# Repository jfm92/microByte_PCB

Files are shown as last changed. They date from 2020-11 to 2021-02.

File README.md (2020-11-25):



This repository contains the schematics and the PCB design of the microByte project with **KiCad 5.1.6.**

The 3D model of the components were obtained from [SnapEDA](https://www.snapeda.com/).

**If you want to know more about the microByte project go to the next link:**
[Github microByte](https://github.com/jfm92/microByte)

## 3D PCB Images

### PCB Front View
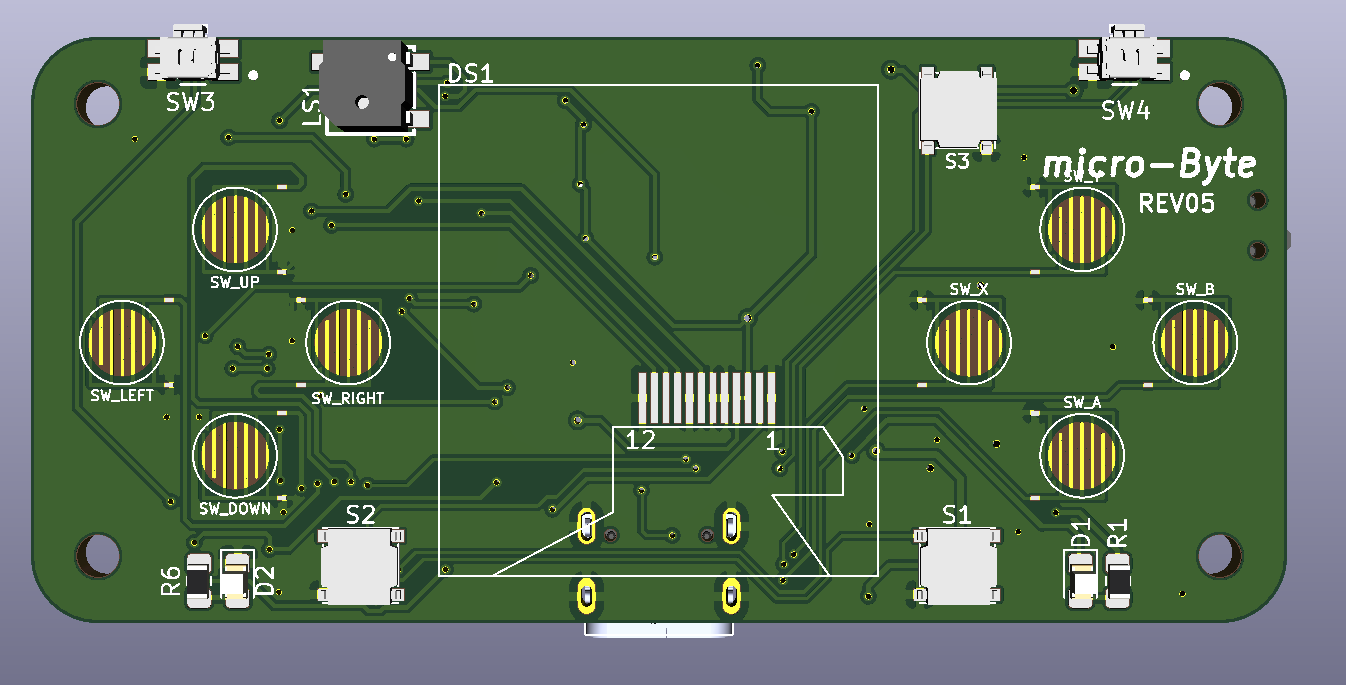
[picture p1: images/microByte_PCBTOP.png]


### PCB Bottom View
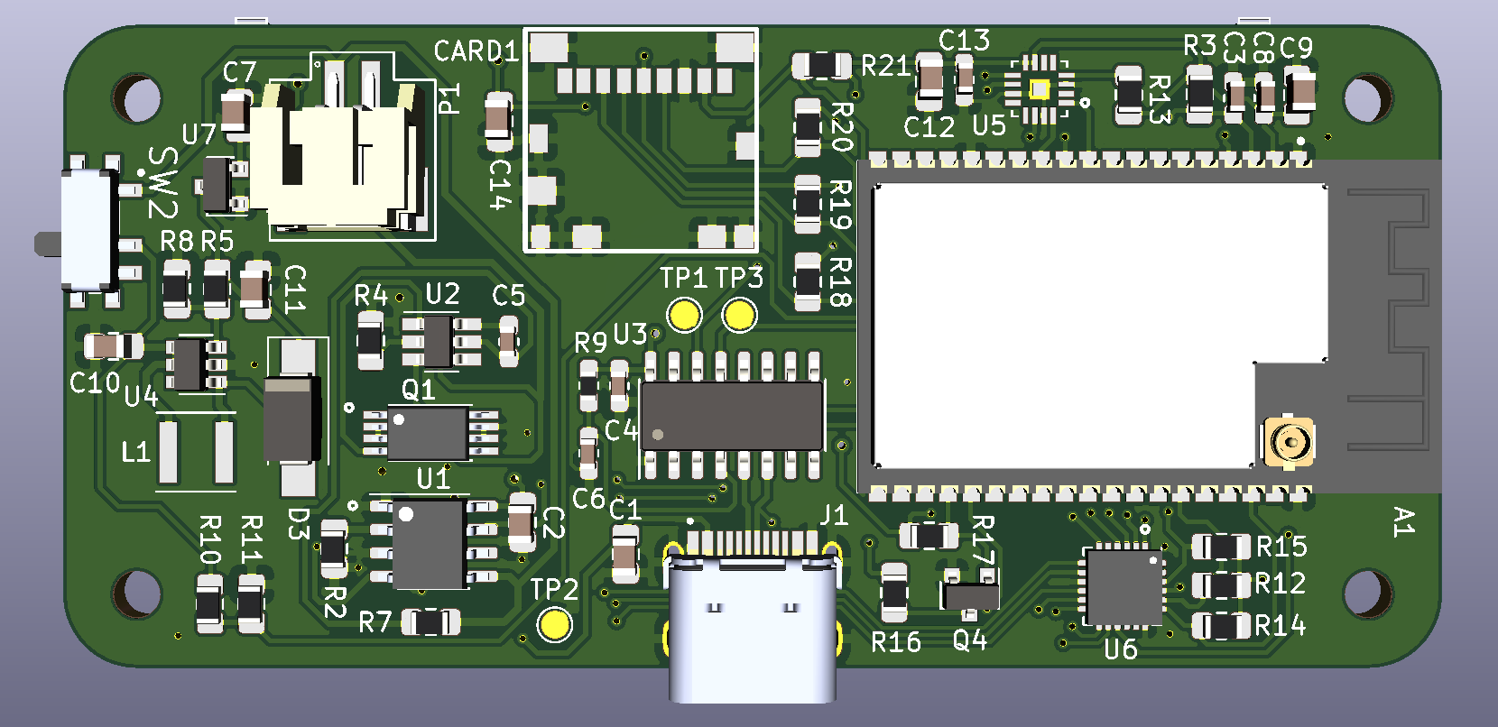
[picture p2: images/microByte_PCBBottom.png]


Note: Some of the compenent 3D models weren't available, thats the reason why they don't appear on the PCB.

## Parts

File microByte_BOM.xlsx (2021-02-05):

Reference | Quantity | Designatation | Package | Link
A1 | 1 | ESP32-WROVER-E (16MB ) | - | Espressif Systems|Espressif Systems ESP32-WROVER-E(16MB)|WIFI Modules|LCSC (https://lcsc.com/product-detail/WIFI-Modules_Espressif-Systems-ESP32-WROVER-E-16MB_C529589.html)
C1 | 1 | 1uF | C_0805_2012Metric
C11 C10 | 2 | 22uF | C_0805_2012Metric
C12 C14 C9 C2 | 4 | 10uF | C_0805_2012Metric
C13 C8 C3 C5 C6 C4 | 6 | 0.1uF | C_0603_1608Metric
C7 | 1 | 10uF | C_0805_2012Metric
CARD1 | 1 | TF-110 | -
D1 D2 | 2 | LED | LED_0805_2012Metric
D3 | 1 | D_Schottky | D_SMA
DS1 | 1 | ST7789 1.3" | -
H1 H2 H3 H4 | 4 | MountingHole | -
J1 | 1 | TYPE-C-31-M-12 | -
L1 | 1 | 22uH | -
LS1 | 1 | Speaker | - | KELIKING|KELIKING KLJ-5030|Buzzers|LCSC (https://lcsc.com/product-detail/Buzzers_KELIKING-KLJ-5030_C201044.html)
P1 | 1 | S2B-PH-SM4-TB | - | Ckmtw(Shenzhen Cankemeng)|Ckmtw(Shenzhen Cankemeng) C132500|Wire To Board / Wire To Wire Connector|LCSC (https://lcsc.com/product-detail/Wire-To-Board-Wire-To-Wire-Connector_Ckmtw-Shenzhen-Cankemeng-C132500_C132500.html)
Q1 | 1 | FS8205A | SOP65P640X120-8N | Fortune Semicon|Fortune Semicon FS8205A|MOSFET|LCSC (https://lcsc.com/product-detail/MOSFET_Fortune-Semicon-FS8205A_C16052.html)
Q4 | 1 | BSS138 | SOT-23
R1 R6 R2 | 3 | 1K | R_0805_2012Metric
R10 | 1 | 12K | R_0805_2012Metric
R11 | 1 | 27K | R_0805_2012Metric
R13 | 1 | 1M | R_0805_2012Metric
R16 | 1 | 10R | R_0805_2012Metric
R17 | 1 | 3K | R_0805_2012Metric
R18 R19 R20 R21 R12 R14 R15 R3 R5 | 9 | 10K | R_0805_2012Metric
R4 | 1 | 1k | R_0805_2012Metric
R7 | 1 | 100R | R_0805_2012Metric
R8 | 1 | 2K | R_0805_2012Metric
R9 | 1 | 0R | R_0805_2012Metric
S1 | 1 | SW_START | -
S2 | 1 | SW_SELECT | -
S3 | 1 | SW_MENU | -
SW10 | 1 | SW_X | -
SW11 | 1 | SW_RIGHT | -
SW12 | 1 | SW_Y | -
SW2 | 1 | PCM12SMTR | - | Korean Hroparts Elec|Korean Hroparts Elec K3-1296S-E2|Toggle Switches|LCSC (https://lcsc.com/product-detail/Toggle-Switches_Korean-Hroparts-Elec-K3-1296S-E2_C136659.html)
SW3 | 1 | SW_L | - | ALPSALPINE|ALPSALPINE SKSCLCE010|Tactile Switches|LCSC (https://lcsc.com/product-detail/Tactile-Switches_ALPS-Electric-SKSCLCE010_C139799.html)
SW4 | 1 | SW_R | - | ALPSALPINE|ALPSALPINE SKSCLCE010|Tactile Switches|LCSC (https://lcsc.com/product-detail/Tactile-Switches_ALPS-Electric-SKSCLCE010_C139799.html)
SW5 | 1 | SW_UP | -
SW6 | 1 | SW_A | -
SW7 | 1 | SW_DOWN | -
SW8 | 1 | SW_B | -
SW9 | 1 | SW_LEFT | -
TP1 | 1 | TP_RST | -
TP2 | 1 | TP_GND | -
TP3 | 1 | TP_IO0 | -
U1 | 1 | TP4056 | ESOP8 | TOPPOWER(Nanjing Extension Microelectronics)|TOPPOWER(Nanjing Extension Microelectronics) TP4056-42-ESOP8|PMIC - Battery Management|LCSC (https://lcsc.com/product-detail/PMIC-Battery-Management_TOPPOWER-Nanjing-Extension-Microelectronics-TP4056-42-ESOP8_C16581.html)
U2 | 1 | FS312F-G | SOT-23-6 | Fortune Semicon|Fortune Semicon FS312F-G|Battery Protection ICs|LCSC (https://lcsc.com/product-detail/Battery-Protection-ICs_Fortune-Semicon-FS312F-G_C82736.html)
U3 | 1 | CH340C | SOIC-16 | WCH(Jiangsu Qin Heng)|WCH(Jiangsu Qin Heng) CH340C|USB ICs|LCSC (https://lcsc.com/product-detail/USB-ICs_WCH-Jiangsu-Qin-Heng-CH340C_C84681.html)
U4 | 1 | MT3608 | SOT-23-6 | XI'AN Aerosemi Tech|XI'AN Aerosemi Tech MT3608|DC-DC Converters|LCSC (https://lcsc.com/product-detail/DC-DC-Converters_XI-AN-Aerosemi-Tech-MT3608_C84817.html)
U5 | 1 | MAX98357AETE+T | TQFN
U6 | 1 | TCA9555RTWR | 24-Pin WQFN
U7 | 1 | MCP1700-3302E_SOT23 | SOT-23

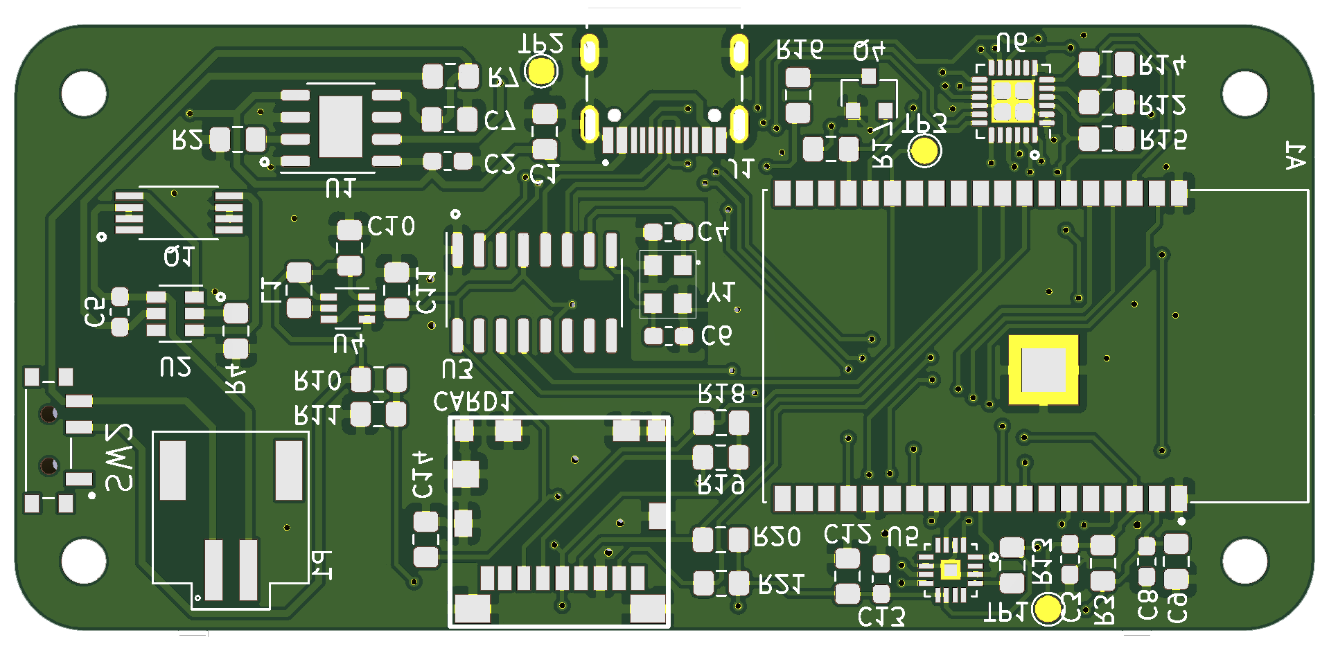
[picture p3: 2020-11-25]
components_3d/micro-Byte_bottom_flipped.png

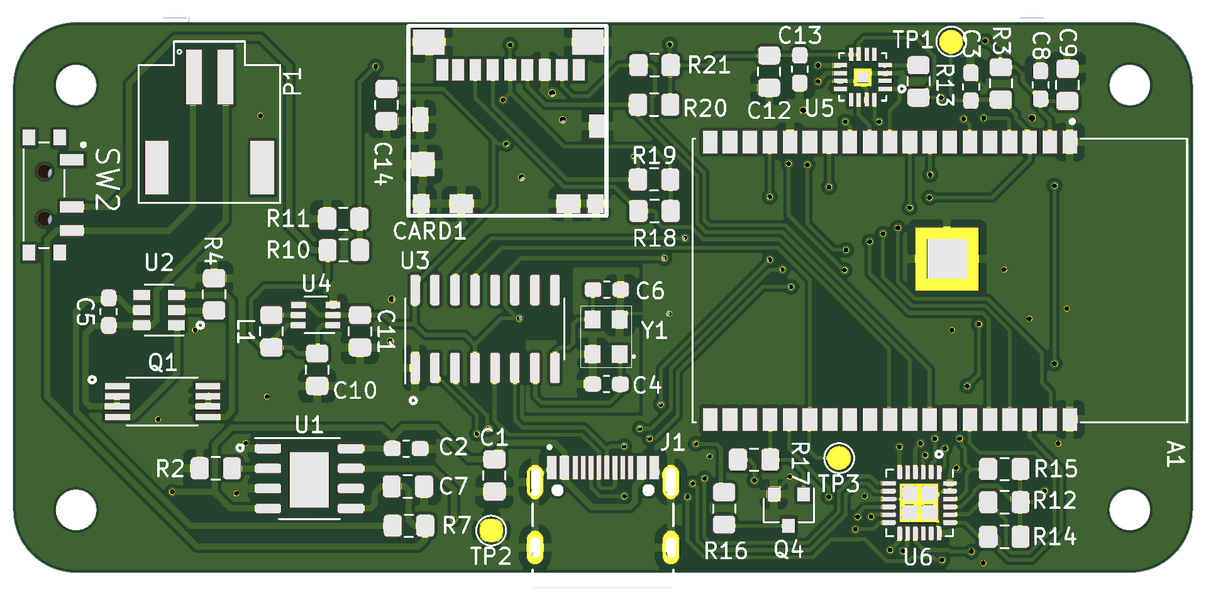
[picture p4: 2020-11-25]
components_3d/micro-Byte_bottom.png

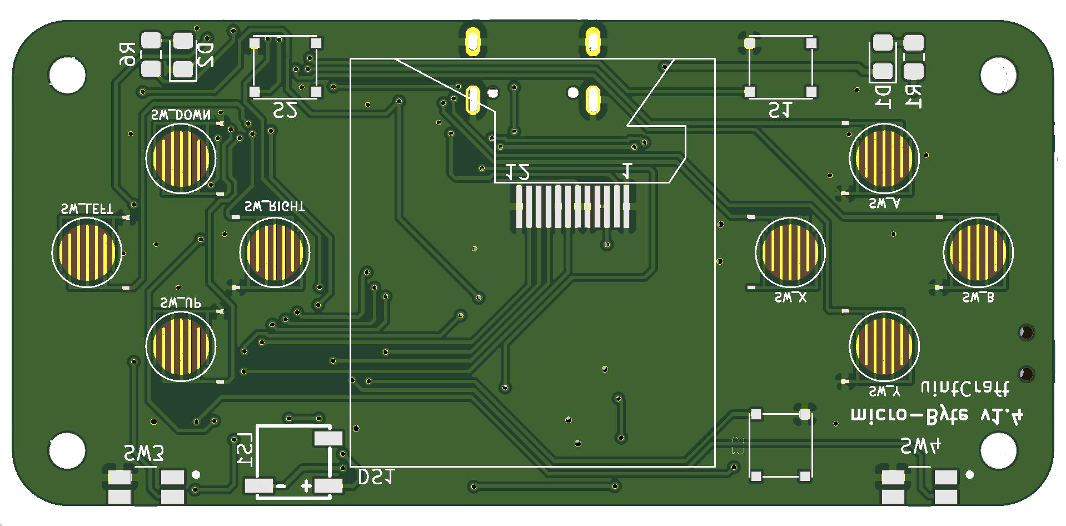
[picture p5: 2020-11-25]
components_3d/micro-Byte_front0_flipped.png

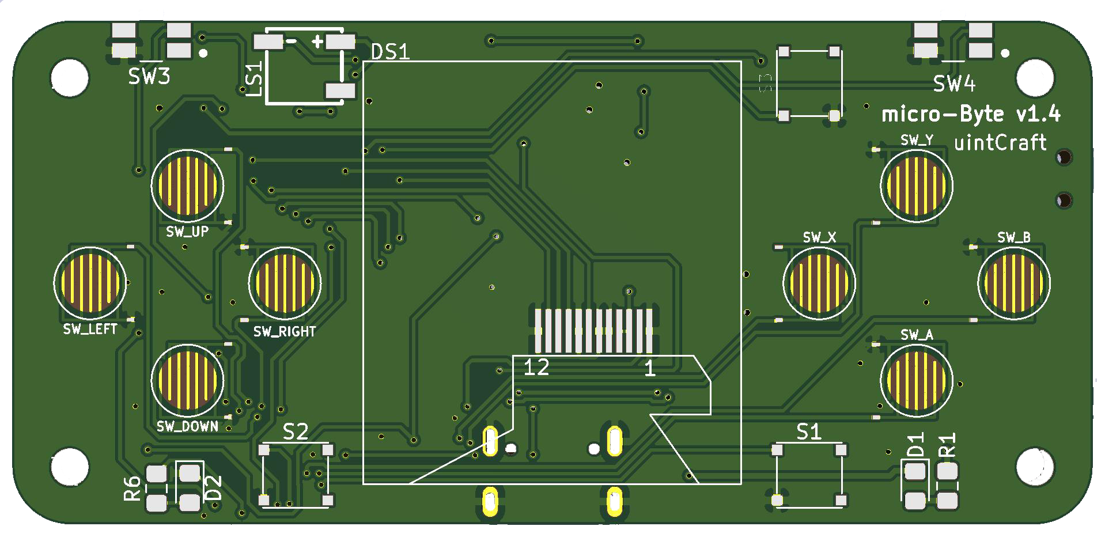
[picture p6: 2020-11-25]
components_3d/micro-Byte_front.png

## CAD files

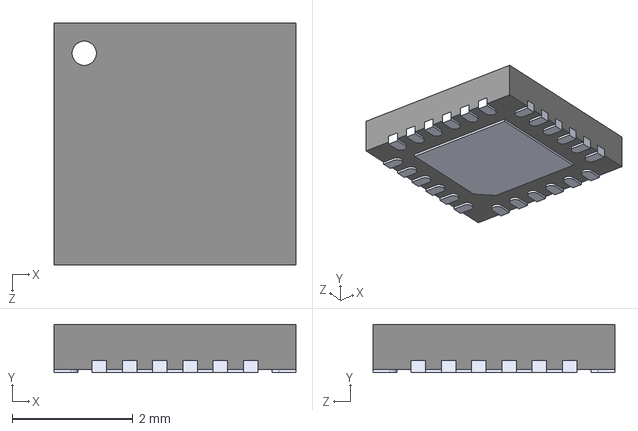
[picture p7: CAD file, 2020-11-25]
components_3d/TCA9555RTWR.STEP
4.00 x 0.8 x 4.00 mm

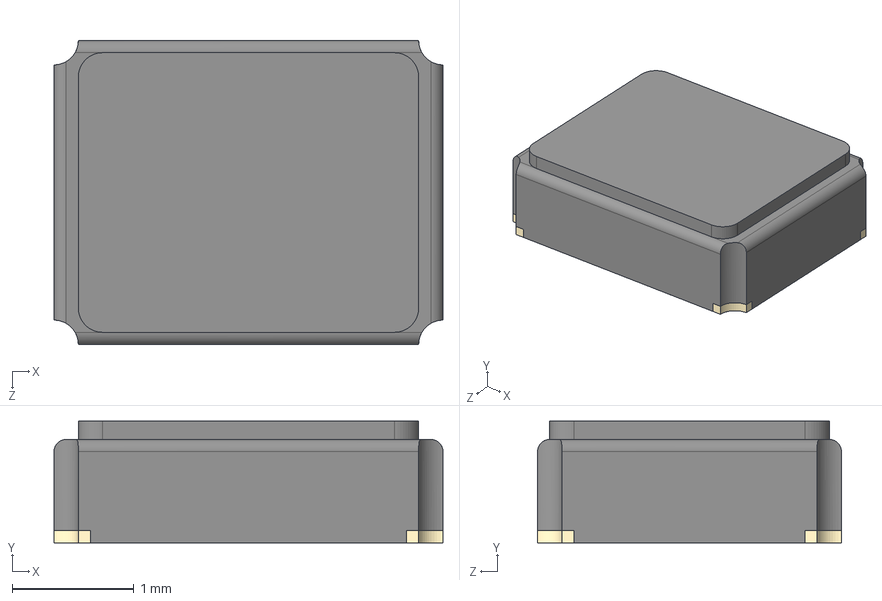
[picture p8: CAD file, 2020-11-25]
components_3d/ABM8-12.000MHZ-B2-T.STEP
3.20 x 1.00 x 2.50 mm

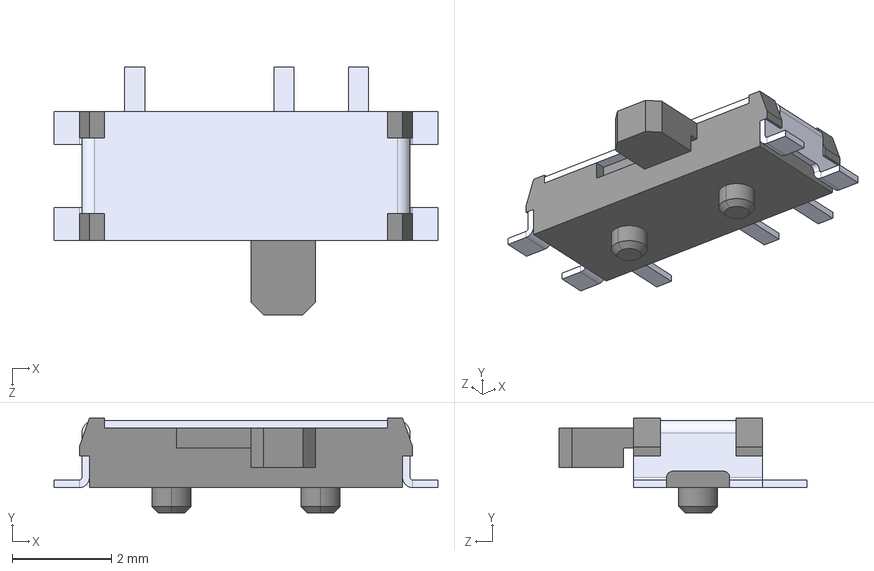
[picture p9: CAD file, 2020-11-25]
components_3d/PCM12SMTR.STEP
7.72 x 1.91 x 4.98 mm

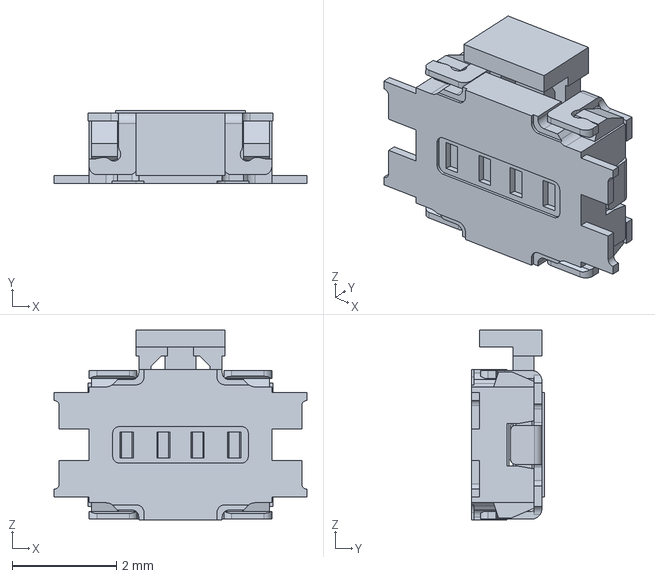
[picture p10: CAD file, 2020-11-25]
components_3d/PTS841GKSMTRLFS.stp
4.85 x 1.40 x 3.64 mm

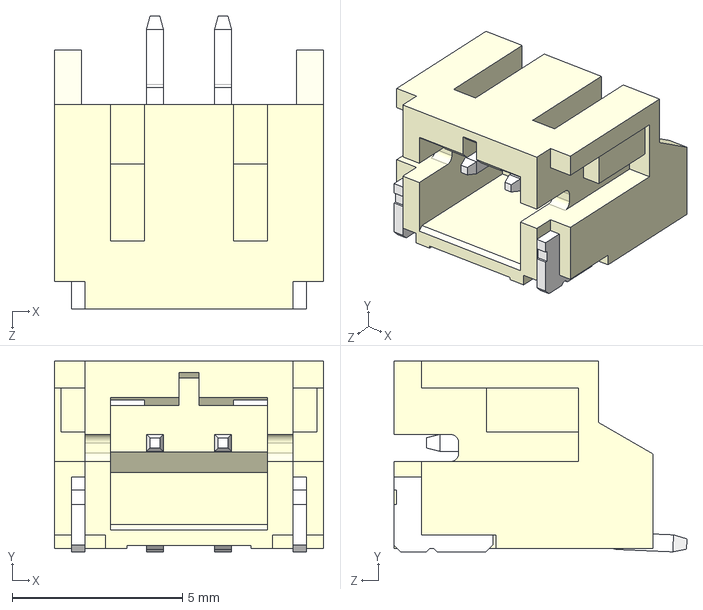
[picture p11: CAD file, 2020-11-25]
components_3d/S2B-PH-SM4-TB(LF)(SN).STEP
7.90 x 5.60 x 8.60 mm

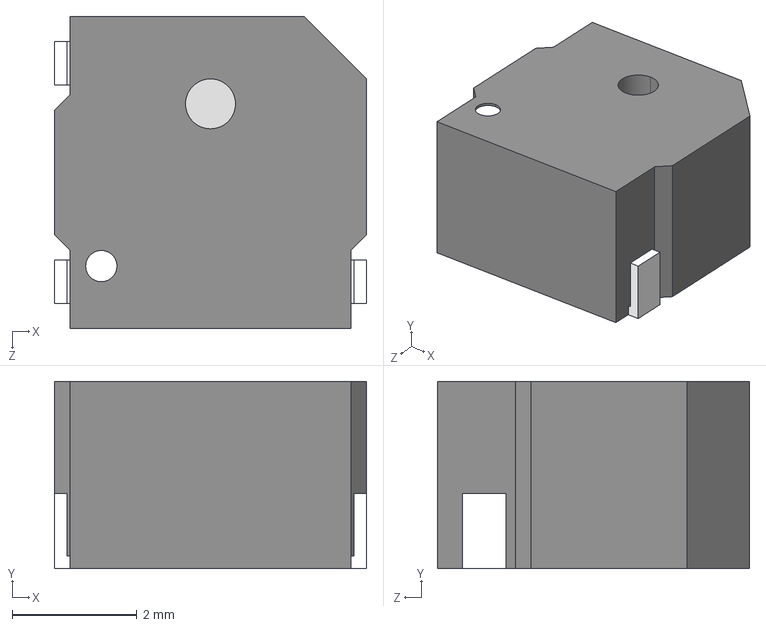
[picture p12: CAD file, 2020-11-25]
components_3d/CUI_DEVICES_CSS-0578-SMT-TR.step
5.00 x 3.00 x 5.00 mm

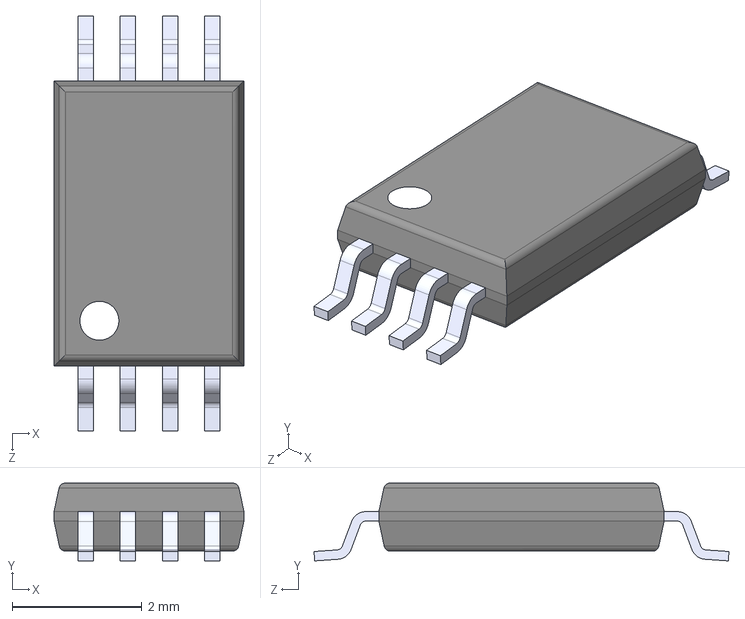
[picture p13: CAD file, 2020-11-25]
components_3d/FS8205A.STEP
2.93 x 1.20 x 6.40 mm

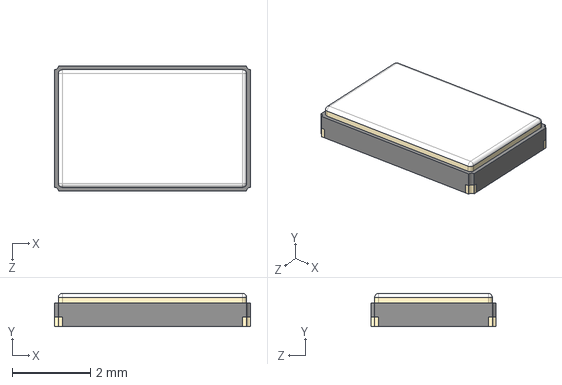
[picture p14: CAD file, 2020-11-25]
components_3d/ECS-120-20-30B-TR.STEP
5.00 x 0.85 x 3.20 mm

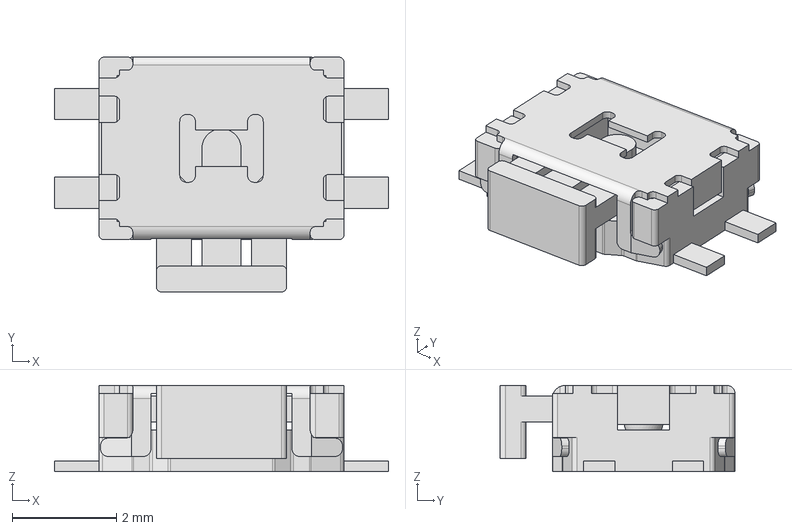
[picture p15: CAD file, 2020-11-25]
components_3d/TL1014AFxxxQG.stp
6.40 x 4.50 x 1.65 mm

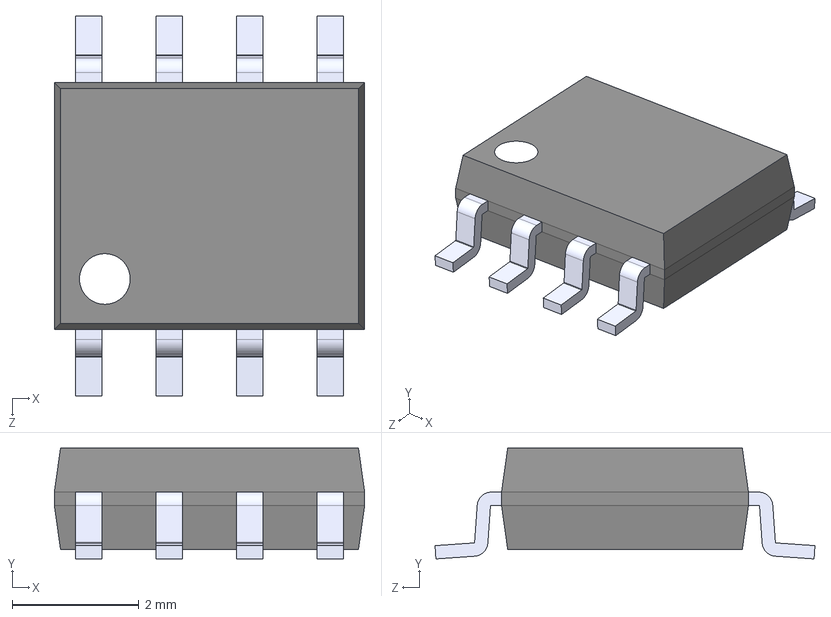
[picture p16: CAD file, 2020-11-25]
components_3d/TP4056.STEP
4.90 x 1.75 x 6.00 mm

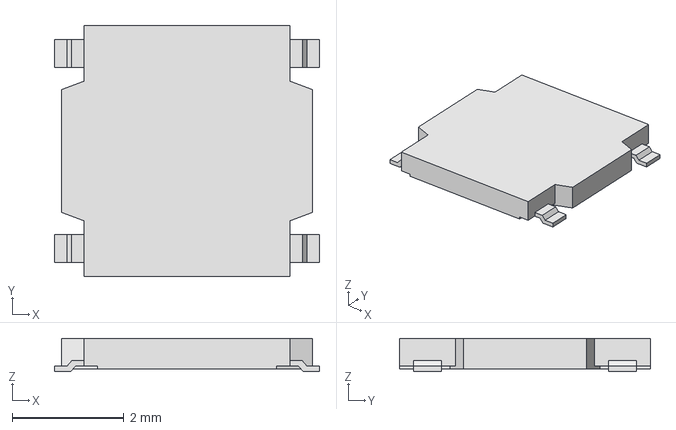
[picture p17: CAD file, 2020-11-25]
components_3d/TL3315NFxxxQ.stp
4.75 x 4.50 x 0.6 mm

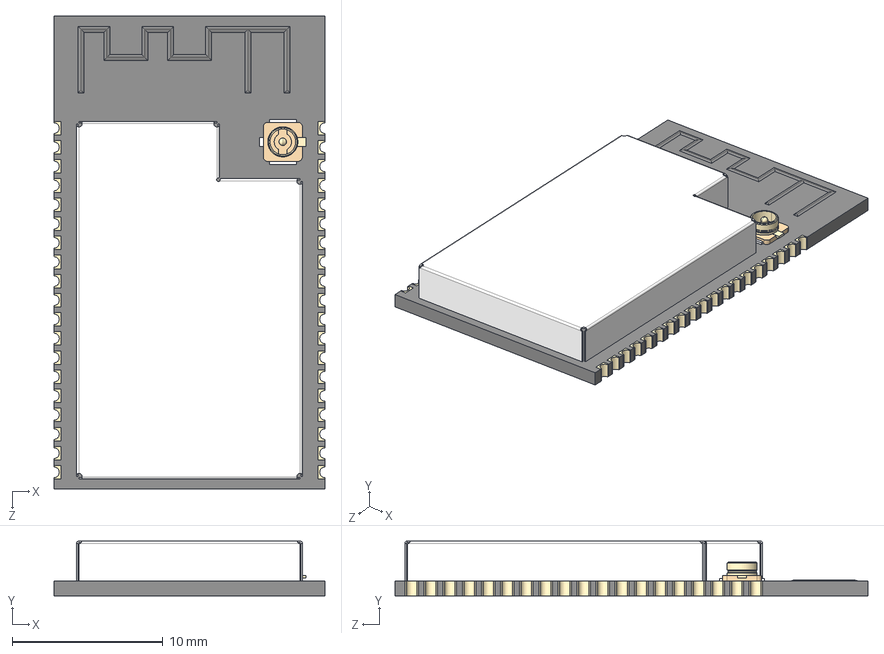
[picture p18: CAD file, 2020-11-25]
components_3d/ESP32-WROVER-I.STEP
18.0 x 3.65 x 31.4 mm

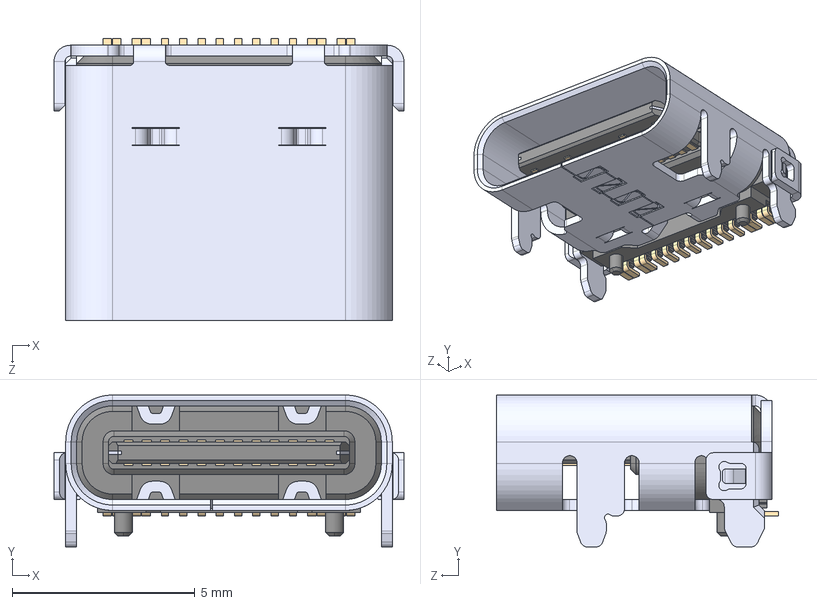
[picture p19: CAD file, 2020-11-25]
components_3d/USB4105-GF.STEP
9.58 x 4.16 x 7.71 mm

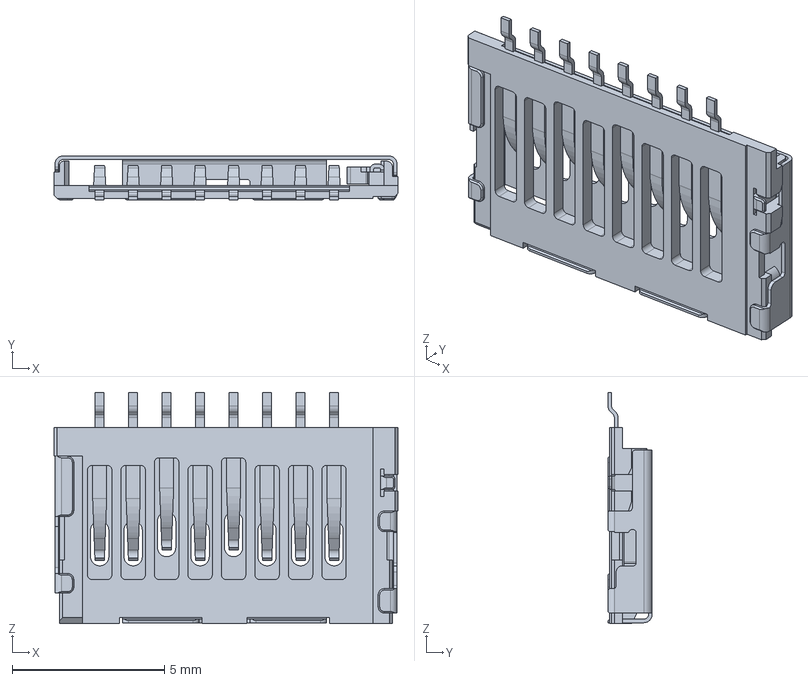
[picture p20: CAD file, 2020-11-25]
components_3d/1051620001.stp
11.3 x 1.45 x 7.60 mm

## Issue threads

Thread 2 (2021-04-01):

About the V3 pin of CH340C

Jiawens, 2021-04-01:
In the schematic, near the CH340C chip, there is a sentence like this:

> R9 brigde to connect to +3.3v.
Is not clear on datatsheet.

I went to search for the datasheet of CH340C, it says:

> 当使用 3.3V 工作电压时，CH340 芯片的 V3 引脚应该与 VCC 引脚相连接，同时输入外部的 3.3V 电源，并且与 CH340 芯片相连接的其它电路的工作电压不能超过 3.3V。

After translation:

> When using 3.3V working voltage, V3 pin of CH340 chip should be connected with VCC pin, and input external 3.3V power supply at the same time, and the working voltage of other circuits connected with CH340 chip should not exceed 3.3V.

It didn't said that R9 should bridge to connect to +3.3V, so I am a little bit doubtful. Will it work when V3 pin is connected to +3.3v directly?

(Sorry for my poor English and bad grammer)

jfm92, 2021-04-08:
Hi Jiawens,
Sorry for the delayed answer, I'm a little busy nowadays.

> It didn't said that R9 should bridge to connect to +3.3V, so I am a little bit doubtful. Will it work when V3 pin is connected to +3.3v directly?

On previous versions of the board, V3 and Vcc were connected, and it worked. But the reason to add a bridge was that the chip was producing an "Electrical noise" and I was suspecting that the datasheet was badly translated, and the information was wrong. (This is the datasheet [Sparkfun translation](https://cdn.sparkfun.com/datasheets/Dev/Arduino/Other/CH340DS1.PDF) )

At this moment I don't connect V3 and VCC, and it works fine. No audible electrical noise, and no issue with RTC and CTS signals.

Maybe this answer can help you too much, but I just can say that it works fine.

redfox67, 2021-04-08:
If i were to add a headphone jack, would I add it before or after the amp to the speaker? does the speaker have an amp or is it in the audio chip?

Jiawens, 2021-04-17:
I see. I will use the same design as yours to avoid electrical noise.
Thank you for your comment. :)

Closed 2021-04-17.

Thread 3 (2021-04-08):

Add headphone jack

redfox67, 2021-04-08:
If I were to add a headphone jack were would I solder it to? I am thinking about using [this one](https://www.amazon.com/Adafruit-Vertical-Breadboard-Friendly-Headphone/dp/B07M7PGL99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).

jfm92, 2021-04-12:
Hi!
Well, I'm not sure if the jack that you're thinking to use fits inside the enclosure, but if you think that it's possible or you can find something a little bit smaller, you need to do the next:

- Solder directly to the driver it's very difficult due to the pads are very small, so I suggest to first unsolder the speaker.
- Once you have unsoldered the speaker, these are the sound output pads:
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

I think that the easiest way, is to add a pair of wires and place the jack on the bottom part of the enclosure because the front has very little space available and might be a real challenge to fit a jack there. Also, I think that can help you a little see the 3D model of the enclosure to visualize the internal space.
https://github.com/jfm92/microByte_case/tree/2df587d479643be42f094e5c9a5782840cb68b26/Enclosure

I hope this message can help you and I'm anxious to see your experiment!

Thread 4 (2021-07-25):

Easily Broken switch

kicker22004, 2021-07-25:
My unit arrived yesterday and was damaged from heat exposure, I've left you a comment on crowdsource with this information, upon reprinting the cases and getting the unit back together the Right toggle feel off the switch taking the inner plunger with it so that switch is going to need to be replaced now, I'm going to redesign the button so that it fits inside the case with two lips instead of one so that the button doesn't need glued to the switch head. I'm hoping that my other one doesn't fail also. And on further inspection my power switch is bent down I'm not sure if it's from heat or the pressure from the case but i'll be replacing it and making changes to the case if needed.

redfox67, 2021-07-25:
I had a similar issue, the right switch was not working on arrival. Overconfident in my making skills I tried to fix it and broke the switch. That is a great idea to do a redesigned button, if you do get that done could I use that file? Also do you know the switches name/number?

kicker22004, 2021-07-25:
> I had a similar issue, the right switch was not working on arrival. Overconfident in my making skills I tried to fix it and broke the switch. That is a great idea to do a redesigned button, if you do get that done could I use that file? Also do you know the switches name/number?

https://lcsc.com/mobile/product-detail/Tactile-Switches_ALPS-Electric-SKSCLCE010_C139799.html
That is the link to the switch, also it seems there was already a button redesign 3 months ago. I printed the new design yesterday but can't test until my switches get here. I know the other switch is going to break trying to remove the printed button so I ordered 5 switches just in case.

redfox67, 2021-07-26:
Thank you, how hard do you think it would be to desolder the switch as opposed to cutting it off?

kicker22004, 2021-07-26:
For me it is very simple but I have a bit of experience working with SMD.

redfox67, 2021-07-26:
Yeah, I ended up crushing the switch then removed it, however when I tried soldering a replacement button I had on hand the continuity check showed that there was a bridge between the control wire and ground. After desoldering and trying to fix it , it still is linked to ground. either I tell the firmware that one of the menu buttons is the right switch or I route a different pin on the u6 to the button which is an even more difficult soldering job. What would you recommend I do?

kicker22004, 2021-07-26:
I would remove your switch and then test the pads, those shouldn't be touching, after that test the switch off the board as well.

redfox67, 2021-07-26:
I tried testing the pads, what I believe to be the problem is that the pad that is connected to the u6 is soldered to the sheet of copper in the pcb that is grounded.

kicker22004, 2021-07-26:
Oh that's unfortunate, I'd reach out to the creator but if you damaged it then it's on you.

jfm92, 2021-07-26:
Hi!

Sorry for taking so long to follow up on this issue.
The U6 is solder the cooper plain to dissipate heat, to unsolder it I recommend using a heat gun instead of an iron solder, it can be very challenging :)
Anyways, I don't fully understand the relation with switch issue and the U6? Are you trying to use the PCB buttons to switch the power?
If it so, I don't recommend you to do so, because the switch just connect the battery circuit with the rest of the rest of PCB so it's just like join to wires.
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

redfox67, 2021-07-26:
Thank you for responding, the issue is the right bumper/trigger thing, What happened is in the schematic the switch is between ground and pin 6 of U6, or the controls IC and if I run a continuity check of those two solder pads they are connected without there even being a switch, which means that in any game that uses that button it will be permanently triggered.

redfox67, 2021-07-26:
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

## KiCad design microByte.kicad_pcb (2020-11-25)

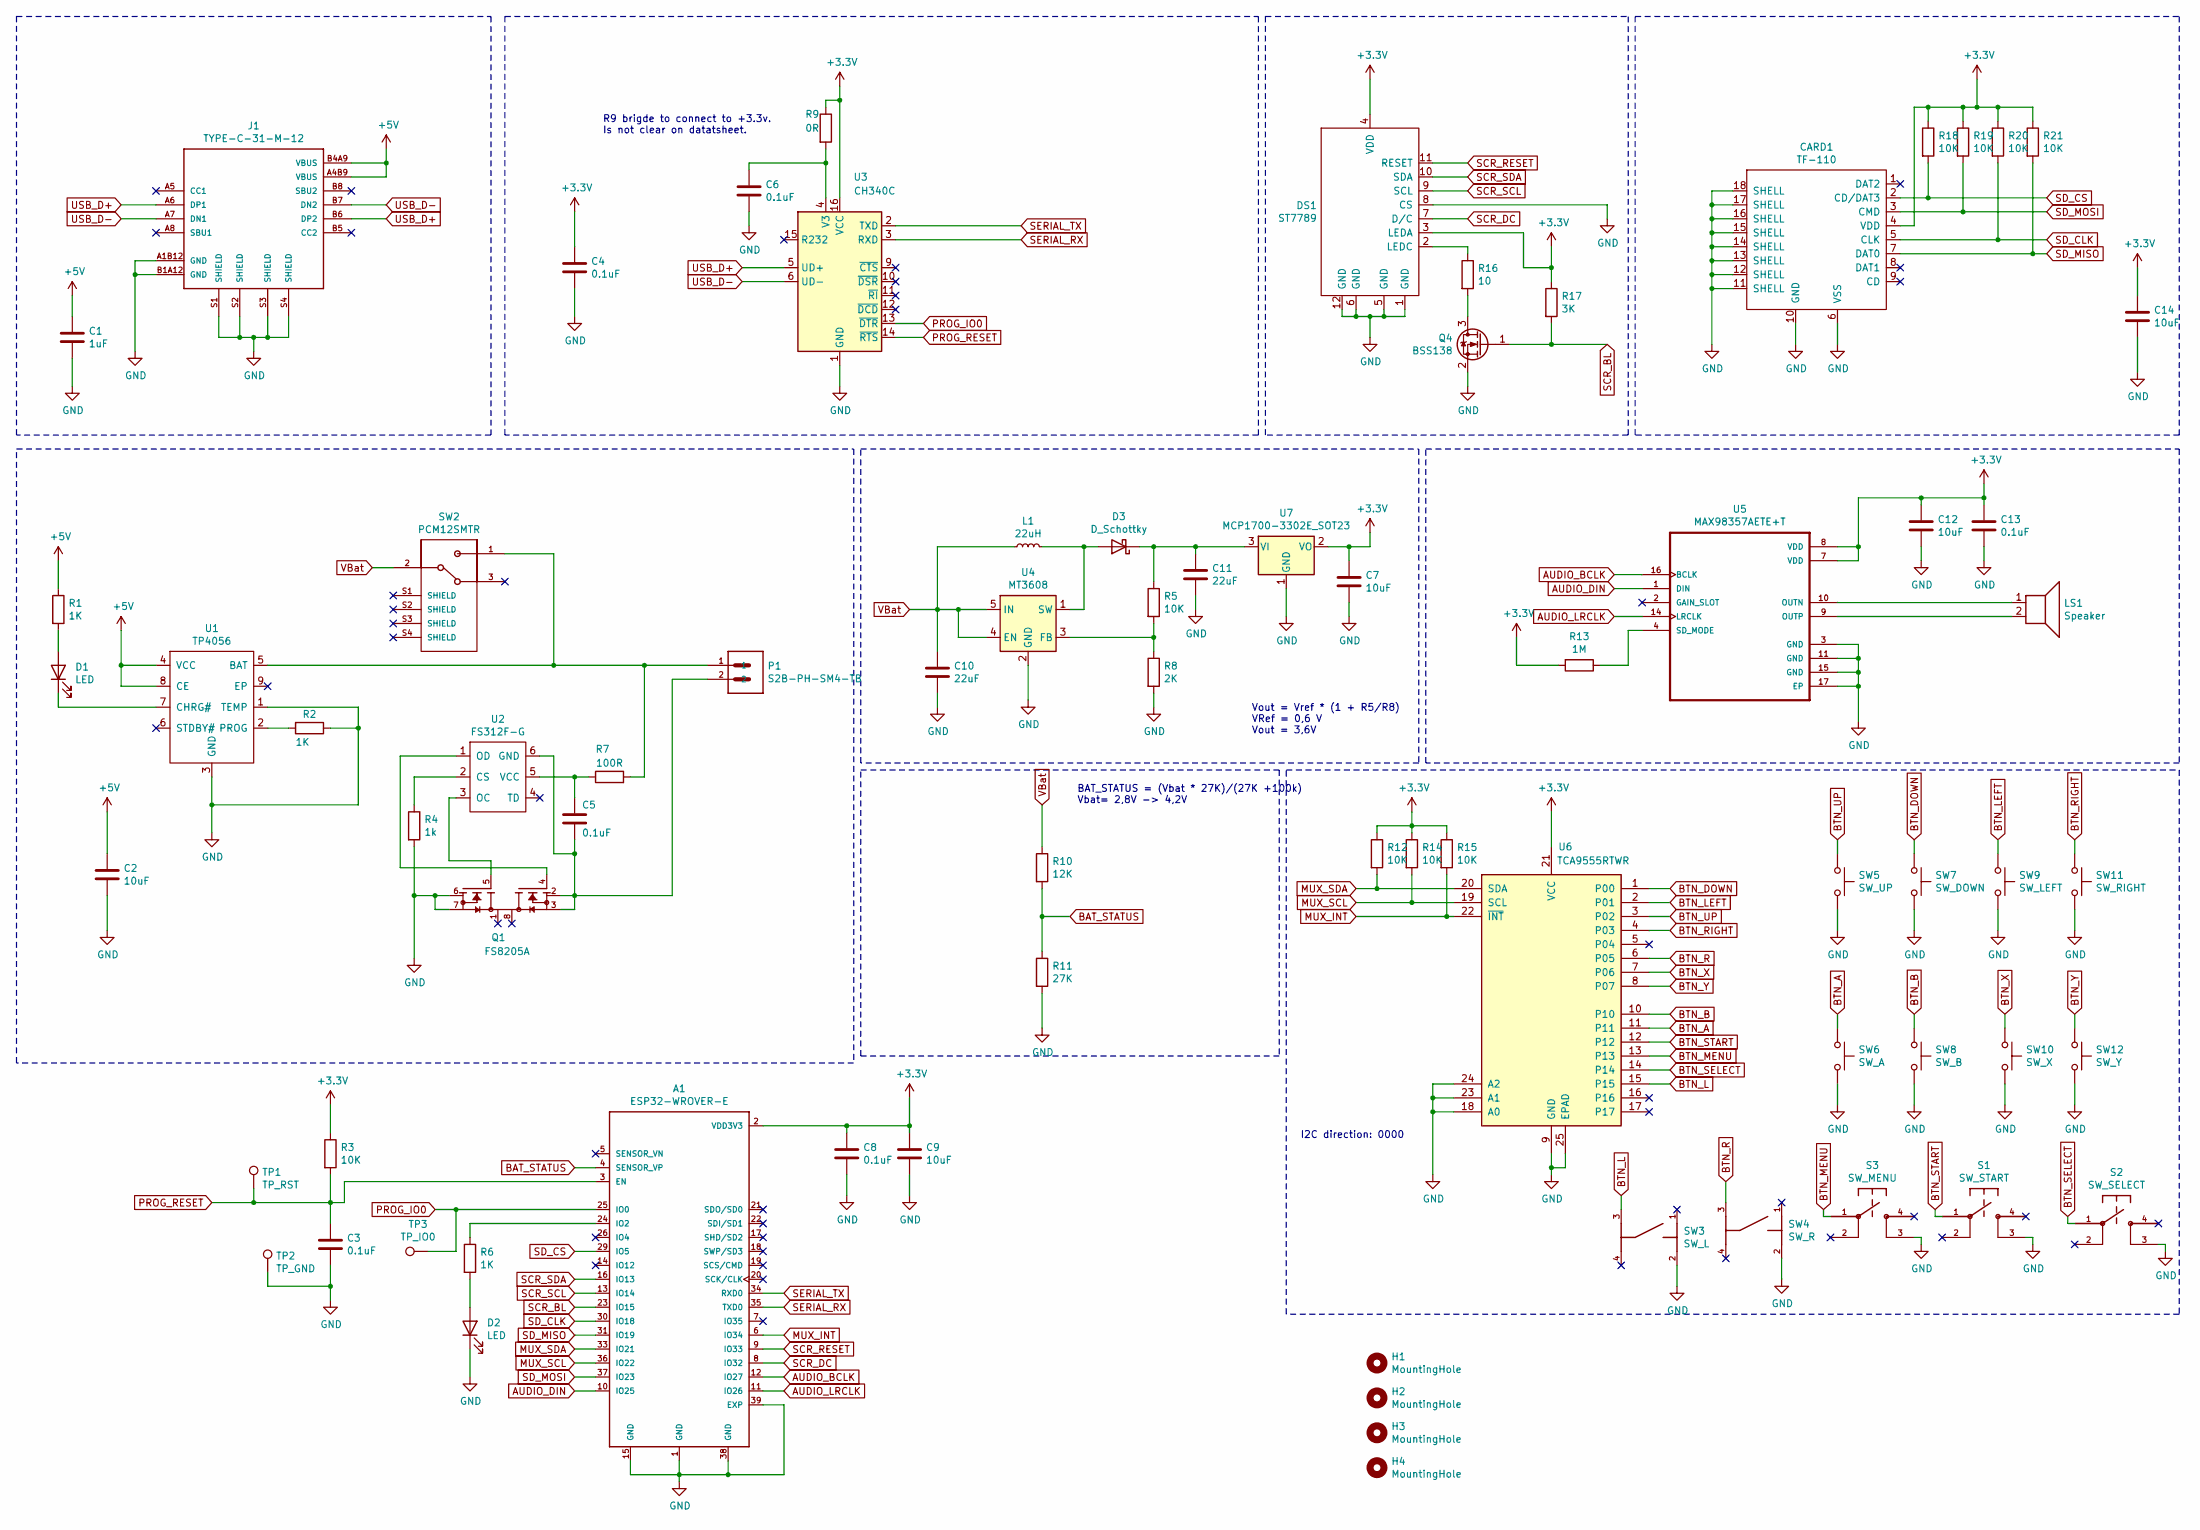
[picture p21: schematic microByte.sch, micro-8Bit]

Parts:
A1: ESP32-WROVER-E; XCVR_ESP32-WROVER-I
C1: 1uF; C_0805_2012Metric_Pad1.15x1.40mm_HandSolder
C2, C9, C12, C14: 10uF; C_0805_2012Metric_Pad1.15x1.40mm_HandSolder
C3, C4, C5, C6, C8, C13: 0.1uF; C_0603_1608Metric_Pad1.05x0.95mm_HandSolder
C7: 10uF; C_0805_2012Metric
C10, C11: 22uF; C_0805_2012Metric_Pad1.15x1.40mm_HandSolder
CARD1: TF-110
D1, D2: LED; LED_0805_2012Metric_Pad1.15x1.40mm_HandSolder
D3: D_Schottky; D_SMA_Handsoldering
DS1: ST7789
H1, H2, H3, H4: MountingHole; MountingHole_2.5mm
J1: TYPE-C-31-M-12; HRO_TYPE-C-31-M-12
L1: 22uH; Sunlord_SPH4012H220MT
LS1: Speaker; KLJ-5030
P1: S2B-PH-SM4-TB; JST_S2B-PH-SM4-TB
Q1: FS8205A; SOP65P640X120-8N
Q4: BSS138; SOT-23
R1, R2, R6: 1K; R_0805_2012Metric_Pad1.15x1.40mm_HandSolder
R3, R5, R12, R14, R15, R18, R19, R20, R21: 10K; R_0805_2012Metric_Pad1.15x1.40mm_HandSolder
R4: 1k; R_0805_2012Metric_Pad1.15x1.40mm_HandSolder
R7: 100R; R_0805_2012Metric_Pad1.15x1.40mm_HandSolder
R8: 2K; R_0805_2012Metric_Pad1.15x1.40mm_HandSolder
R9: 0R; R_0603_1608Metric_Pad1.05x0.95mm_HandSolder
R10: 12K; R_0805_2012Metric_Pad1.15x1.40mm_HandSolder
R11: 27K; R_0805_2012Metric_Pad1.15x1.40mm_HandSolder
R13: 1M; R_0805_2012Metric_Pad1.15x1.40mm_HandSolder
R16: 10; R_0805_2012Metric_Pad1.15x1.40mm_HandSolder
R17: 3K; R_0805_2012Metric_Pad1.15x1.40mm_HandSolder
S1: SW_START; TL3315NF100Q
S2: SW_SELECT; TL3315NF100Q
S3: SW_MENU; TL3315NF100Q
SW2: PCM12SMTR; SW_PCM12SMTR
SW3: SW_L; SW_434331013822
SW4: SW_R; SW_434331013822
SW5: SW_UP; BUTTON-CONDUCTIVE
SW6: SW_A; BUTTON-CONDUCTIVE
SW7: SW_DOWN; BUTTON-CONDUCTIVE
SW8: SW_B; BUTTON-CONDUCTIVE
SW9: SW_LEFT; BUTTON-CONDUCTIVE
SW10: SW_X; BUTTON-CONDUCTIVE
SW11: SW_RIGHT; BUTTON-CONDUCTIVE
SW12: SW_Y; BUTTON-CONDUCTIVE
TP1: TP_RST; TestPoint_Pad_D1.5mm
TP2: TP_GND; TestPoint_Pad_D1.5mm
TP3: TP_IO0; TestPoint_Pad_D1.5mm
U1: TP4056
U2: FS312F-G; SOT-23-6_Handsoldering
U3: CH340C; SOIC-16_3.9x9.9mm_P1.27mm
U4: MT3608; SOT-23-6
U5: MAX98357AETE+T; QFN50P300X300X80-17N
U6: TCA9555RTWR
U7: MCP1700-3302E_SOT23; SOT-23

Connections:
+3V3: A1.2 (VDD3V3), C4.1, C7.1, C8.1, C9.1, C12.1, C13.1, C14.1, CARD1.4 (VDD), DS1.3 (LEDA), DS1.4 (VDD), R3.1, R9.1, R12.1, R13.2, R14.1, R15.1, R17.1, R18.1, R19.1, R20.1, R21.1, U3.16 (VCC), U5.7 (VDD), U5.8 (VDD), U6.21 (VCC), U7.2 (VO)
+5V: C1.1, C2.1, J1.A4B9 (VBUS), J1.B4A9 (VBUS), R1.1, U1.4 (VCC), U1.8 (CE)
AUDIO_BCLK: A1.12 (IO27), U5.16 (BCLK)
AUDIO_DIN: A1.10 (IO25), U5.1 (DIN)
AUDIO_LRCLK: A1.11 (IO26), U5.14 (LRCLK)
BAT_STATUS: A1.4 (SENSOR_VP), R10.2, R11.1
BTN_A: SW6.1, U6.11
BTN_B: SW8.1, U6.10
BTN_DOWN: SW7.1, U6.1 (P00)
BTN_L: SW3.3, U6.15
BTN_LEFT: SW9.1, U6.2 (P01)
BTN_MENU: S3.1, U6.13
BTN_R: SW4.3, U6.6 (P05)
BTN_RIGHT: SW11.1, U6.4 (P03)
BTN_SELECT: S2.1, U6.14
BTN_START: S1.1, U6.12
BTN_UP: SW5.1, U6.3 (P02)
BTN_X: SW10.1, U6.7 (P06)
BTN_Y: SW12.1, U6.8 (P07)
GND: A1.1 (GND), A1.15 (GND), A1.38 (GND), A1.39 (EXP), C1.2, C2.2, C3.2, C4.2, C6.2, C7.2, C8.2, C9.2, C10.2, C11.2, C12.2, C13.2, C14.2, CARD1.6 (VSS), CARD1.10 (GND), CARD1.11 (SHELL), CARD1.12 (SHELL), CARD1.13 (SHELL), CARD1.14 (SHELL), CARD1.15 (SHELL), CARD1.16 (SHELL), CARD1.17 (SHELL), CARD1.18 (SHELL), D2.1 (K), DS1.1 (GND), DS1.5 (GND), DS1.6 (GND), DS1.8 (CS), DS1.12 (GND), J1.A1B12 (GND), J1.B1A12 (GND), J1.S1 (SHIELD), J1.S2 (SHIELD), J1.S3 (SHIELD), J1.S4 (SHIELD), Q1.6, Q1.7, Q4.2 (S), R2.1, R4.2, R8.2, R11.2, S1.3, S2.3, S3.3, SW3.2, SW4.2, SW5.2, SW6.2, SW7.2, SW8.2, SW9.2, SW10.2, SW11.2, SW12.2, TP2.1, U1.1 (TEMP), U1.3 (GND), U3.1 (GND), U4.2 (GND), U5.3 (GND), U5.11 (GND), U5.15 (GND), U5.17 (EP), U6.9 (GND), U6.18 (A0), U6.23 (A1), U6.24 (A2), U6.25 (EPAD), U7.1 (GND)
MUX_INT: A1.6 (IO34), R15.2, U6.22 (~INT)
MUX_SCL: A1.36 (IO22), R14.2, U6.19 (SCL)
MUX_SDA: A1.33 (IO21), R12.2, U6.20 (SDA)
unnamed: A1.24 (IO2), R6.1
unnamed: C5.1, R7.1, U2.5 (VCC)
unnamed: C5.2, P1.2, Q1.2, Q1.3, U2.6 (GND)
unnamed: C6.1, R9.2, U3.4 (V3)
unnamed: C11.1, D3.1 (K), R5.1, U7.3 (VI)
unnamed: D1.1 (K), U1.7 (CHRG#)
unnamed: D1.2 (A), R1.2
unnamed: D2.2 (A), R6.2
unnamed: D3.2 (A), L1.2, U4.1 (SW)
unnamed: DS1.2 (LEDC), R16.1
unnamed: LS1.1, U5.10 (OUTN)
unnamed: LS1.2, U5.9 (OUTP)
unnamed: P1.1, R7.2, SW2.1, U1.5 (BAT)
unnamed: Q1.4, U2.1 (OD)
unnamed: Q1.5, U2.3 (OC)
unnamed: Q4.3 (D), R16.2
unnamed: R2.2, U1.2 (PROG)
unnamed: R4.1, U2.2 (CS)
unnamed: R5.2, R8.1, U4.3 (FB)
unnamed: R13.1, U5.4 (SD_MODE)
PROG_IO0: A1.25 (IO0), TP3.1, U3.13 (~DTR)
PROG_RESET: A1.3 (EN), C3.1, R3.2, TP1.1, U3.14 (~RTS)
SCR_BL: A1.23 (IO15), Q4.1 (G), R17.2
SCR_DC: A1.8 (IO32), DS1.7 (D/C)
SCR_RESET: A1.9 (IO33), DS1.11 (RESET)
SCR_SCL: A1.13 (IO14), DS1.9 (SCL)
SCR_SDA: A1.16 (IO13), DS1.10 (SDA)
SD_CLK: A1.30 (IO18), CARD1.5 (CLK), R20.2
SD_CS: A1.29 (IO5), CARD1.2 (CD/DAT3), R18.2
SD_MISO: A1.31 (IO19), CARD1.7 (DAT0), R21.2
SD_MOSI: A1.37 (IO23), CARD1.3 (CMD), R19.2
SERIAL_RX: A1.35 (TXD0), U3.3 (RXD)
SERIAL_TX: A1.34 (RXD0), U3.2 (TXD)
USB_D+: J1.A6 (DP1), J1.B6 (DP2), U3.5 (UD+)
USB_D-: J1.A7 (DN1), J1.B7 (DN2), U3.6 (UD-)
VBat: C10.1, L1.1, R10.1, SW2.2, U4.4 (EN), U4.5 (IN)

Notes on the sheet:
I2C direction: 0000
R9 brigde to connect to +3.3v. Is not clear on datatsheet.
Vout = Vref * (1 + R5/R8) VRef = 0,6 V Vout = 3,6V
BAT_STATUS = (Vbat * 27K)/(27K +100k) Vbat= 2,8V -> 4,2V

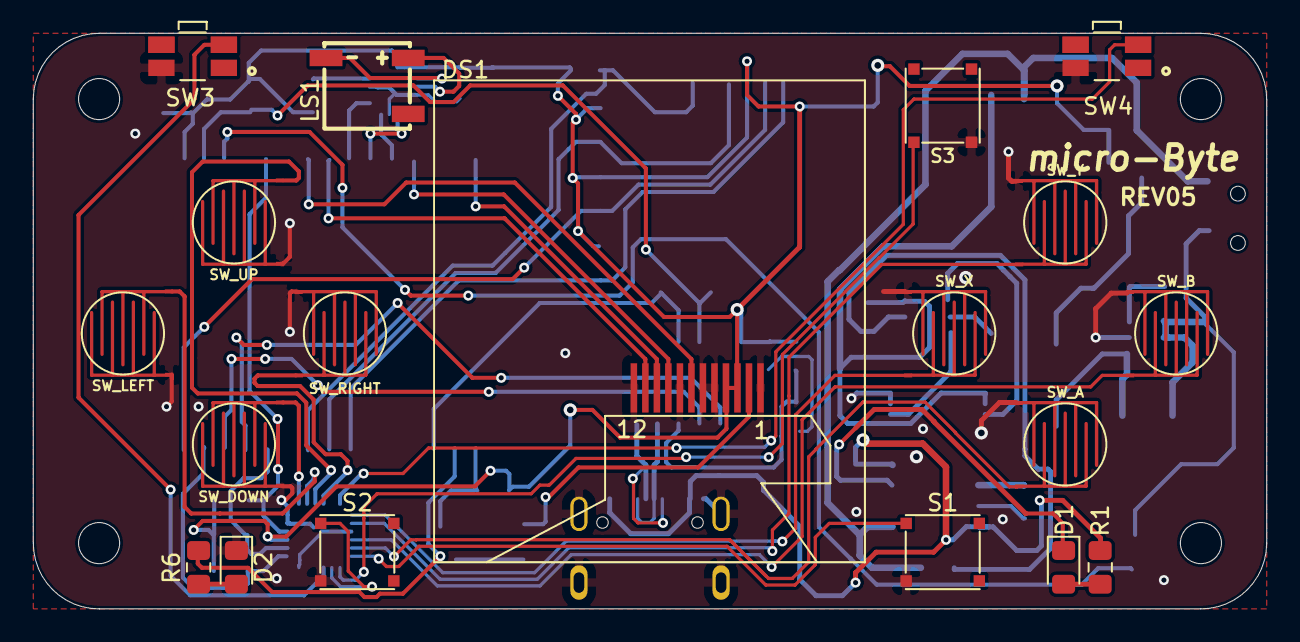
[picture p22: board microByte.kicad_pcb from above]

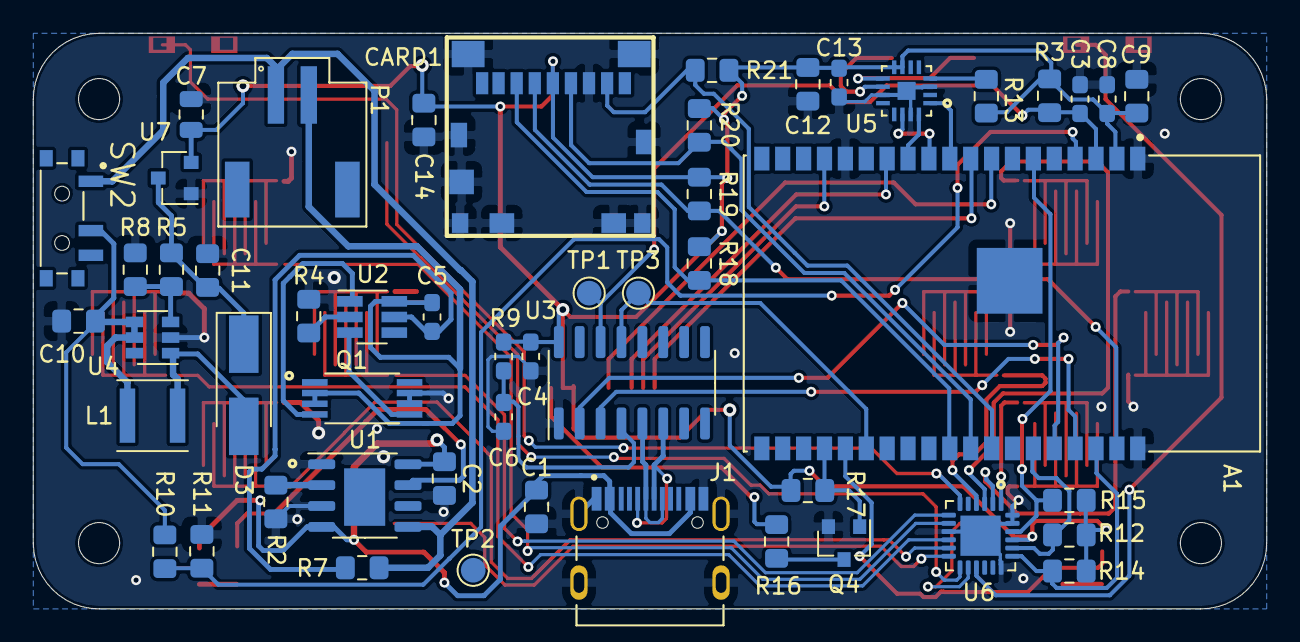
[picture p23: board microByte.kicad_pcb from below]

Board: 2 copper layers, 75.0 x 35.0 mm, 75 parts (52 on the bottom side), 59 nets.

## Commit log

2020-11-25 microByte_PCB v1.5
    [1051620001.stp, ABM8-12.000MHZ-B2-T.STEP, CUI_DEVICES_CSS-0578-SMT-TR.step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]
2021-02-05 Addind BOM with links to strange components
    [microByte_BOM.xlsx]

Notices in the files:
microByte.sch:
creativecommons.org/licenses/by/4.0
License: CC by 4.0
